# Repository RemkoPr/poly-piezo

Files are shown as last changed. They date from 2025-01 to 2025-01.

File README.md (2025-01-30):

# PolyPiezo

This repo contains the PCB design files for the wireless, modular, flexible piezoresistive skin sensor described in [Conveying Emotions to Robots through Touch and Sound](https://arxiv.org/abs/2412.03300), Qiaoqiao Ren, Remko Proesmans, et al, [Best Paper award at ICSR2024](https://icsr2024.dk/index.php/paper-nominees-and-awards/). Please contact remko.proesmans@ugent.be if you'd like support with implementing the design.

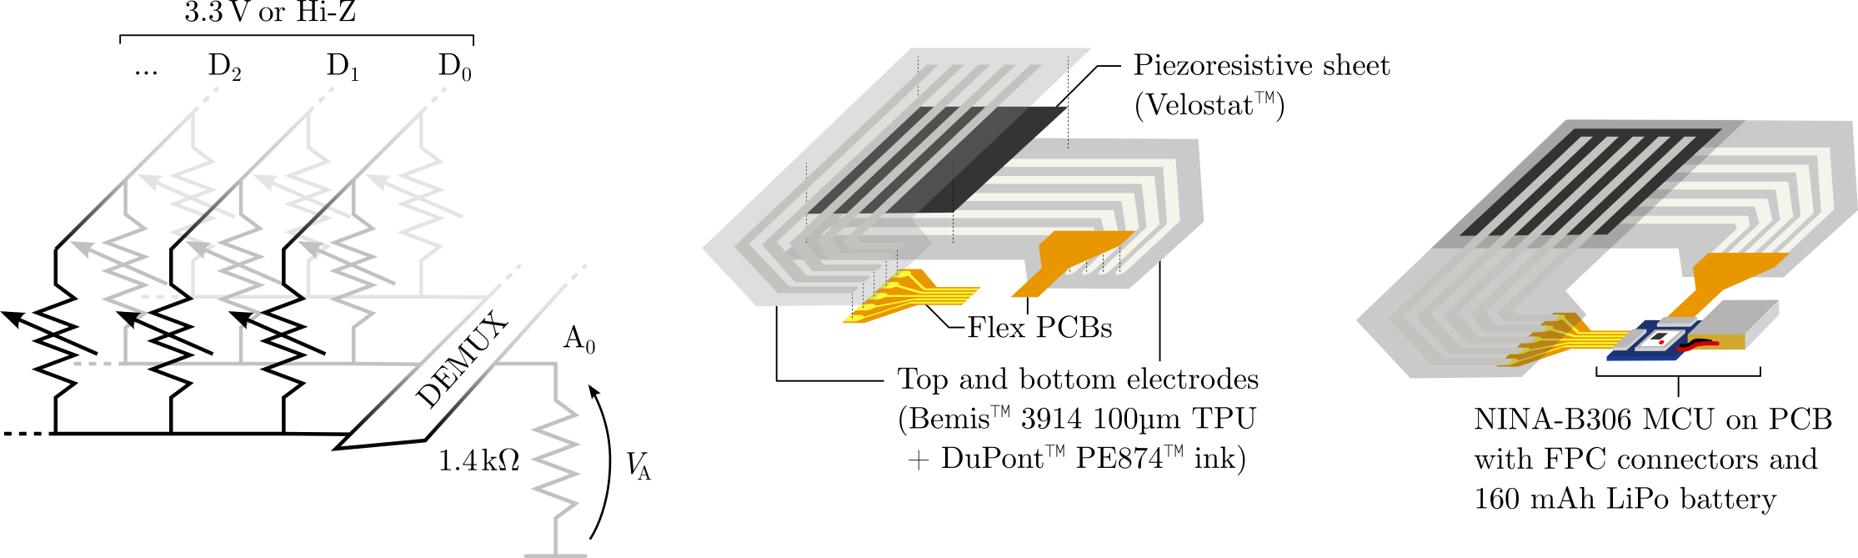
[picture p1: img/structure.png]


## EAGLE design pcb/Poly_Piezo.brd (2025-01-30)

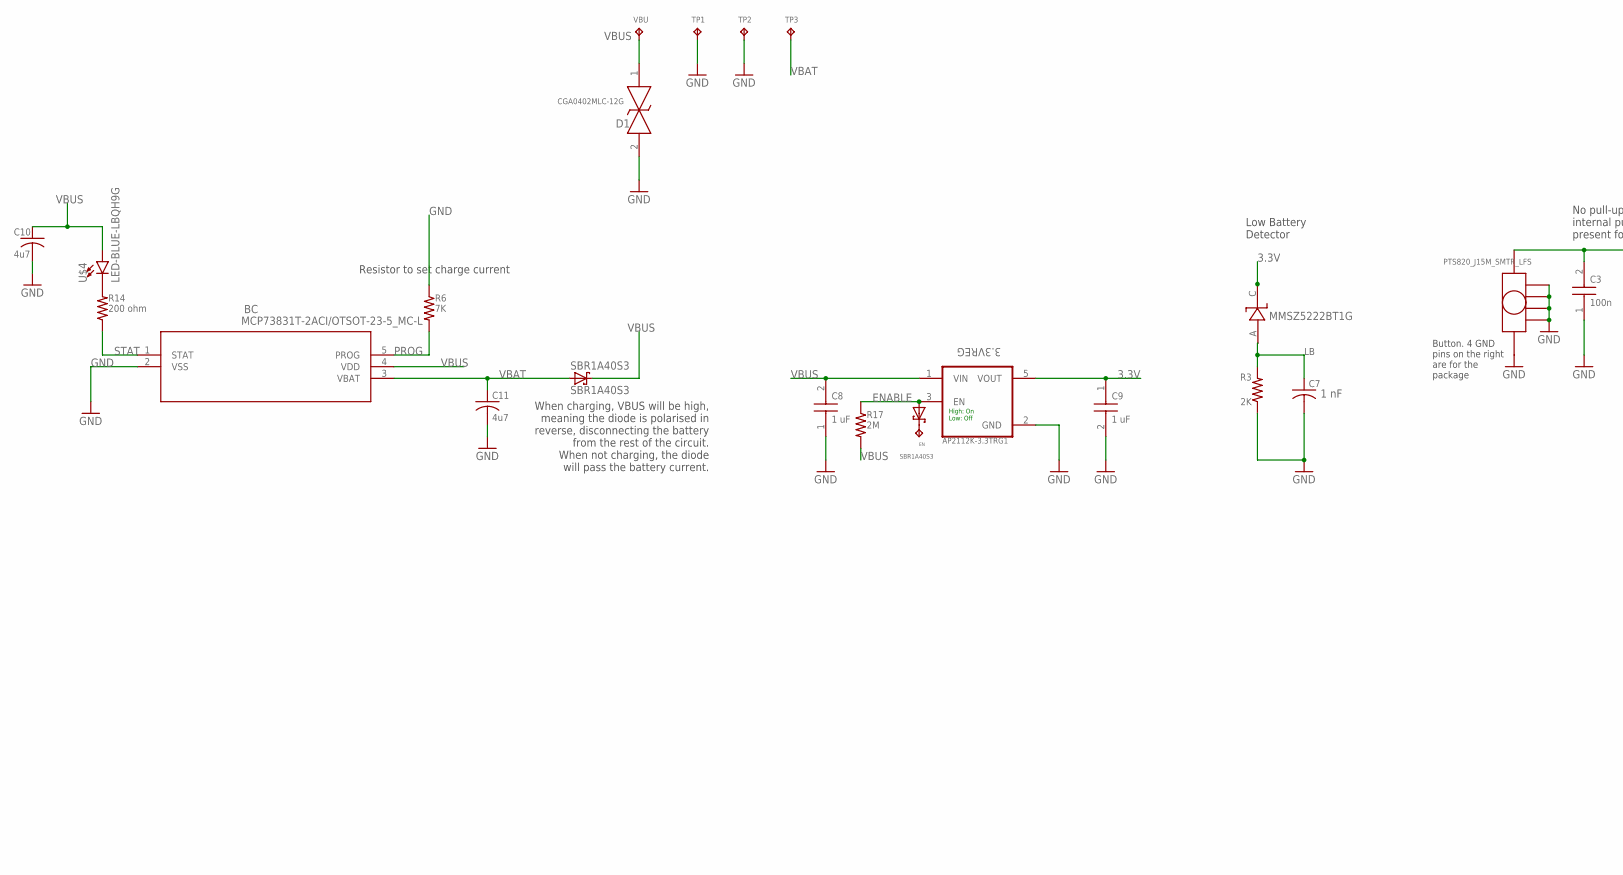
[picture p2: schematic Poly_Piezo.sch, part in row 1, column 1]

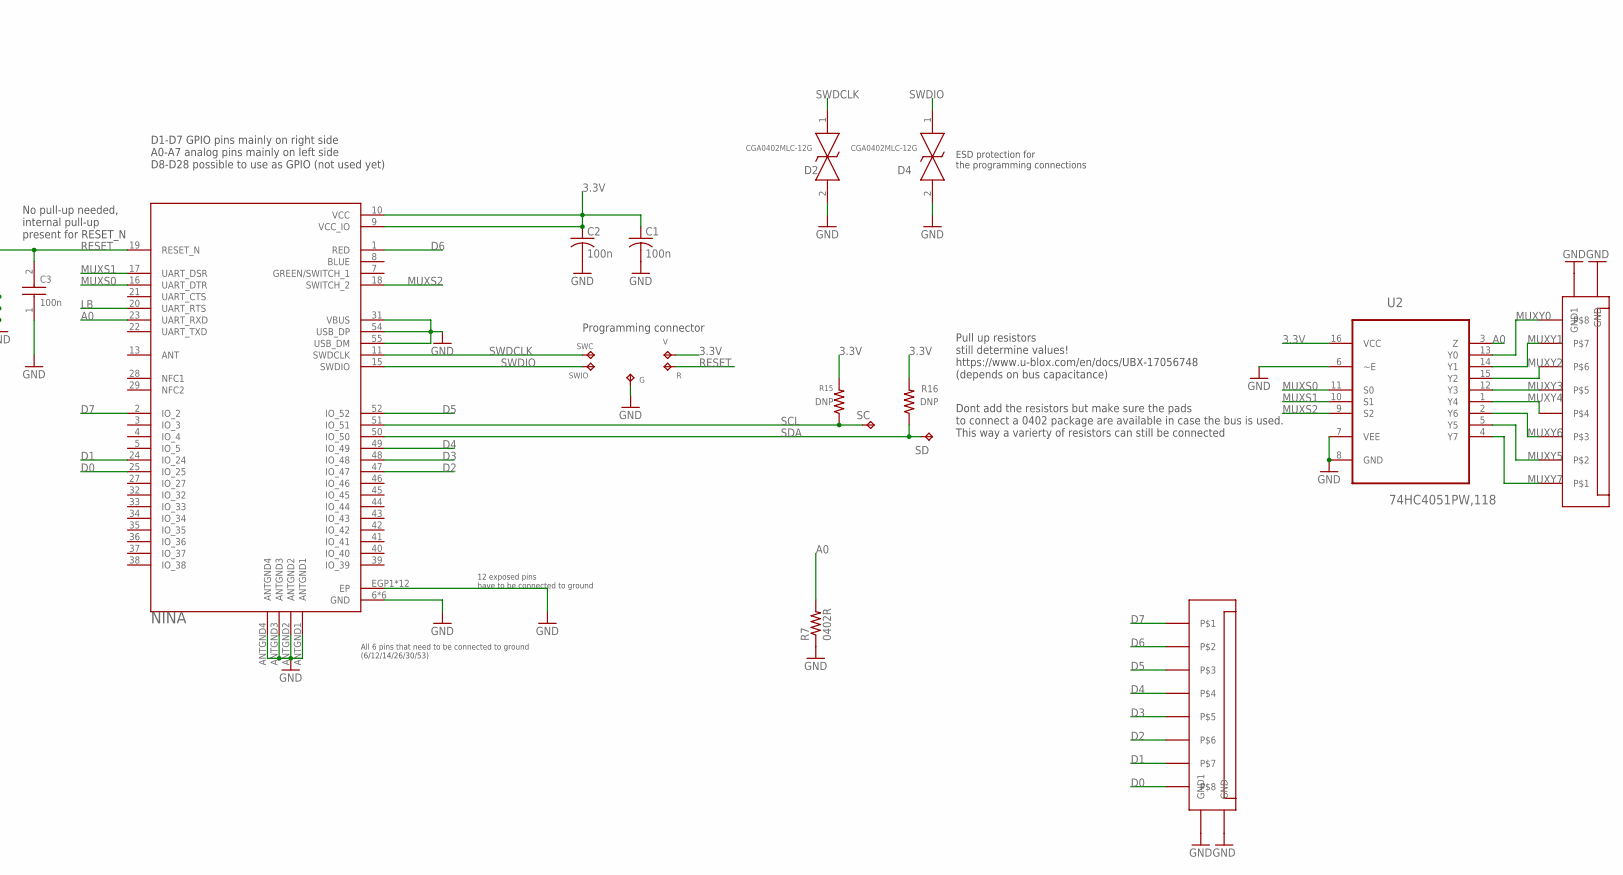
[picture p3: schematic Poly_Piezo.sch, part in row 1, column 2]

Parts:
3.3VREG: AP2112K-3.3TRG1; SOT95P285X140-5N
BC: MCP73831T-2ACI/OTSOT-23-5_MC-L; SOT-23-5_MC-L
BUTTON: PTS820_J15M_SMTR_LFS; PTS820_J15
C1, C2: 100n; C0402
C3: 100n; CAPC1005X33N
C7: 1 nF; C0402
C8, C9: 1 uF; CAPC1005X33N
C10, C11: 4u7; C0402
D1, D2, D4: CGA0402MLC-12G; CGA0402MLC12G
EN: CUSTOM_HOLE1; CUSTOM_HOLE
G: TPB1,27; B1,27
MMSZ5222BT1G: MMSZ5222BT1G; SOD−123
R: TPB1,27; B1,27
R3: 2K; RESC1005X40N
R6: 7K; RESC1005X40N
R7: 0402R; RESC1005X40N
R14: 200 ohm; RESC1005X40N
R15, R16: DNP; RESC1005X40N
R17: 2M; RESC1005X40N
SBR1A40S3: SBR1A40S3; SOD323
SC: CUSTOM_HOLE1; CUSTOM_HOLE
SD: CUSTOM_HOLE1; CUSTOM_HOLE
SWC: TPB1,27; B1,27
SWIO: TPB1,27; B1,27
TP1, TP2, TP3: CUSTOM_HOLE1; CUSTOM_HOLE
U1: NINA; XCVR_NINA-B306
U2: 74HC4051PW,118; SOP65P640X110-16N
U$1, U$3: XF3M(1)-0815-1B
U$2: SBR1A40S3; SOD323
U$4: LED-BLUE-LBQH9G; LBQH9G-0402
V: TPB1,27; B1,27
VBU: CUSTOM_HOLE1; CUSTOM_HOLE

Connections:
3.3V: 3.3VREG.5 (VOUT), C1.1, C2.1, C9.1, MMSZ5222BT1G.C, R15.2, R16.2, U1.9 (VCC_IO), U1.10 (VCC), U2.16 (VCC), V.TP
A0: R7.2, U1.23 (UART_RXD), U2.3 (Z)
D0: U1.25 (IO_25), U$1.P$8
D1: U1.24 (IO_24), U$1.P$7
D2: U1.47 (IO_47), U$1.P$6
D3: U1.48 (IO_48), U$1.P$5
D4: U1.49 (IO_49), U$1.P$4
D5: U1.52 (IO_52), U$1.P$3
D6: U1.1 (RED), U$1.P$2
D7: U1.2 (IO_2), U$1.P$1
ENABLE: 3.3VREG.3 (EN), R17.1, U$2.A
GND: 3.3VREG.2 (GND), BC.2 (VSS), BUTTON.1, BUTTON.P$1, BUTTON.P$2, BUTTON.P$3, BUTTON.P$4, C1.2, C2.2, C3.1, C7.2, C8.1, C9.2, C10.2, C11.2, D1.2, D2.2, D4.2, G.TP, R3.1, R6.1, R7.1, TP1.P$1, TP2.P$1, U1.6 (GND), U1.12 (GND), U1.14 (GND), U1.26 (GND), U1.30 (GND), U1.31 (VBUS), U1.53 (GND), U1.54 (USB_DP), U1.55 (USB_DM), U1.ANTGND1, U1.ANTGND2, U1.ANTGND3, U1.ANTGND4, U1.EGP1 (EP), U1.EGP2 (EP), U1.EGP3 (EP), U1.EGP4 (EP), U1.EGP5 (EP), U1.EGP6 (EP), U1.EGP7 (EP), U1.EGP8 (EP), U1.EGP9 (EP), U1.EGP10 (EP), U1.EGP11 (EP), U1.EGP12 (EP), U2.6 (~E), U2.7 (VEE), U2.8 (GND), U$1.P$9 (GND1), U$1.P$10 (GND), U$3.P$9 (GND1), U$3.P$10 (GND)
LB: C7.1, MMSZ5222BT1G.A, R3.2, U1.20 (UART_RTS)
MUXS0: U1.16 (UART_DTR), U2.11 (S0)
MUXS1: U1.17 (UART_DSR), U2.10 (S1)
MUXS2: U1.18 (SWITCH_2), U2.9 (S2)
MUXY0: U2.13 (Y0), U$3.P$8
MUXY1: U2.14 (Y1), U$3.P$7
MUXY2: U2.15 (Y2), U$3.P$6
MUXY3: U2.12 (Y3), U$3.P$5
MUXY4: U2.1 (Y4), U$3.P$4
MUXY5: U2.5 (Y5), U$3.P$2
MUXY6: U2.2 (Y6), U$3.P$3
MUXY7: U2.4 (Y7), U$3.P$1
unnamed: R14.2, U$4.C
unnamed: EN.P$1, U$2.C
PROG: BC.5 (PROG), R6.2
RESET: BUTTON.2, C3.2, R.TP, U1.19 (RESET_N)
SCL: R15.1, SC.P$1, U1.51 (IO_51)
SDA: R16.1, SD.P$1, U1.50 (IO_50)
STAT: BC.1 (STAT), R14.1
SWDCLK: D2.1, SWC.TP, U1.11 (SWDCLK)
SWDIO: D4.1, SWIO.TP, U1.15 (SWDIO)
VBAT: BC.3 (VBAT), C11.1, SBR1A40S3.A, TP3.P$1
VBUS: 3.3VREG.1 (VIN), BC.4 (VDD), C8.2, C10.1, D1.1, R17.2, SBR1A40S3.C, U$4.A, VBU.P$1

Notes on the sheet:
Low Battery Detector
High: On Low: Off
When charging, VBUS will be high, meaning the diode is polarised in reverse, disconnecting the battery from the rest of the circuit. When not charging, the diode will pass the battery current.
Resistor to set charge current
D1-D7 GPIO pins mainly on right side A0-A7 analog pins mainly on left side D8-D28 possible to use as GPIO (not used yet)
12 exposed pins have to be connected to ground
All 6 pins that need to be connected to ground (6/12/14/26/30/53)
Pull up resistors still determine values! https://www.u-blox.com/en/docs/UBX-17056748 (depends on bus capacitance)
Dont add the resistors but make sure the pads to connect a 0402 package are available in case the bus is used. This way a varierty of resistors can still be connected
No pull-up needed, internal pull-up present for RESET_N
Programming connector
Button. 4 GND pins on the right are for the package
ESD protection for the programming connections

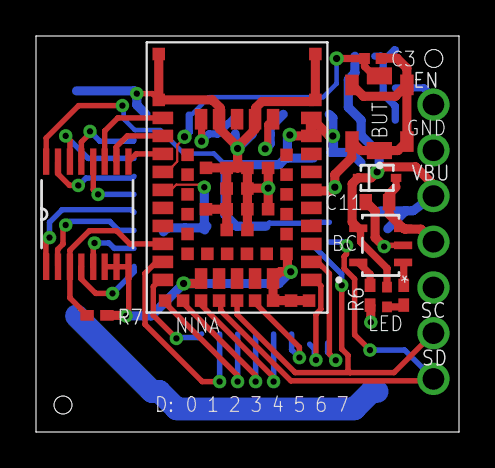
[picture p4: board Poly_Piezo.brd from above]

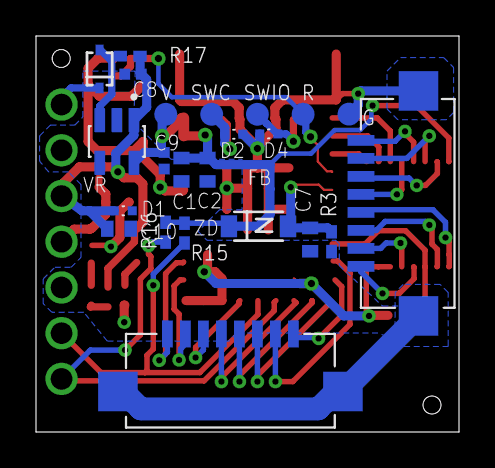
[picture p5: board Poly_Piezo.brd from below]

Board: 2 copper layers, 23.5 x 22.0 mm, 41 parts (24 on the bottom side), 35 nets.

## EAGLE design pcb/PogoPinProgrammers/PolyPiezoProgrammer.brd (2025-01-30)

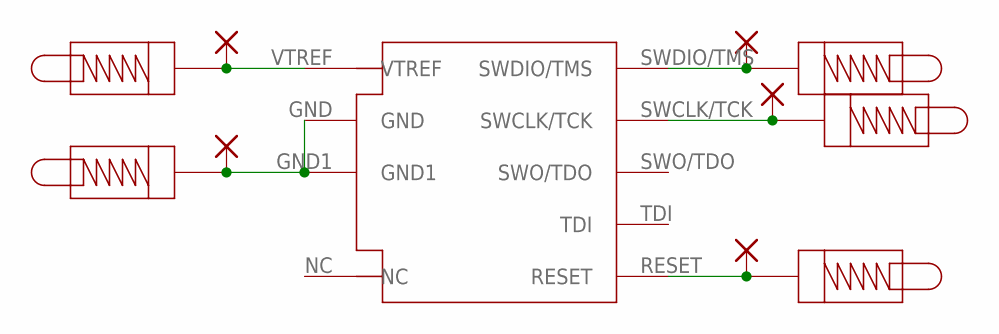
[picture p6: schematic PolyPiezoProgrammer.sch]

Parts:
PAD1, PAD2, PAD3, PAD4, PAD5: WIREPAD2,15/1,0; 2,15/1,0
U$1, U$2, U$3, U$4, U$5: 0930-0-15-20-75-14-11-0
U$6: JLINK_IF

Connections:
unnamed: PAD2.1, U$1.P$1, U$6.VTREF
unnamed: PAD1.1, U$2.P$1, U$6.GND, U$6.GND1
unnamed: PAD5.1, U$3.P$1, U$6.SWDIO/TMS
unnamed: PAD4.1, U$4.P$1, U$6.SWCLK/TCK
unnamed: PAD3.1, U$5.P$1, U$6.RESET

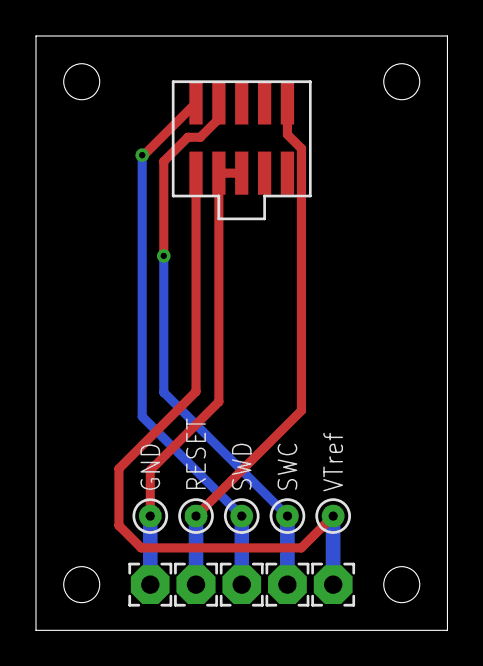
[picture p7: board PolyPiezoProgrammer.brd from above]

Board: 2 copper layers, 22.9 x 33.0 mm, 11 parts (0 on the bottom side), 5 nets.

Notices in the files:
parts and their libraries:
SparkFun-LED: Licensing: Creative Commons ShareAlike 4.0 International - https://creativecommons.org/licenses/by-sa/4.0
